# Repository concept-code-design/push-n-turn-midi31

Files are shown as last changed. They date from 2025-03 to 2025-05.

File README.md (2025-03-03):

# Push-n-Turn 31

Push-n-Turn 31 is a USB MIDI controller with 3 keyboard switches (RedDragon low profile), a rotary encoder and 3/4 RGB leds (WS8212).

The device sports a USB type-C connector and requires no device drivers on Mac or PC.

The keys can be configured (via MIDI messages, or the configurator) to produce notes, CC codes (momentary or toggle mode). The encoder produces 0..127 on a configurable CC channel. The encoder button produces 127/0 on a CC channel of choice.
Each switch has an RGB led that shows the state of the switch.
The device uses a modified midi library for CH55x devices made by mi:muz 

## Configuring the keys
Configuration of the keys can be done by sending midi codes to the device.
You can use python midiutil for this (https://github.com/sourcebox/midiutil).

start prog
./midiutil.py -d 1 -w 186 102 42

end prog
./midiutil.py -d 1 -w 186 102 43

module type
./midiutil.py -d 1 -w 186 102 44
returns: (10, 103, INSTRUMENT_TYPE);

firmware version
./midiutil.py -d 1 -w 186 102 45
returns (10, 104, FW_VERSION) 10 for version 1.0

show configuration
./midiutil.py -d 1 -w 186 102 46
returns the config of each of the 6 buttons, the rotary knob and rotary encoder

show stepsize 
./midiutil.py -d 1 -w 186 102 47
returns (10, 105, encStepSize)

show MIDI channel 
./midiutil.py -d 1 -w 186 102 48
returns (10, 106, MIDIChannel)

reboot in firmware update mode
./midiutil.py -d 1 -w 186 102 49

programming keys
./midiutil.py -d 1 -w 186 102 42
./midiutil.py -d 1 -w 186 11 60
./midiutil.py -d 1 -w 186 22 30
./midiutil.py -d 1 -w 186 33 9
./midiutil.py -d 1 -w 186 24 15
./midiutil.py -d 1 -w 186 5 24
./midiutil.py -d 1 -w 186 102 43

## Links & References

* [mi:muz:ch55x Tiny USB MIDI Library for Ch55xduino](https://github.com/mimuz/mimuz-ch55x)
* [push-n-turn-midi61](https://github.com/concept-code-design/push-n-turn-midi61)

# License

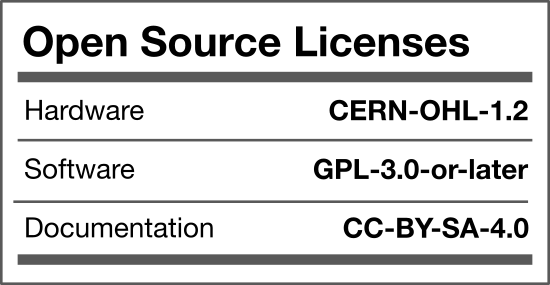
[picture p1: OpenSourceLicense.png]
OpenSourceLicense


Concept & Code invests time and resources providing this open source design, please support them and open-source hardware by purchasing products from Etsy or Tindie!

Designed by Ronald Leenes.

Firmware released under an GNU AGPL v3.0 license. See the LICENSE file for more information.

Hardware released under an CERN Open Hardware Licence v1.2. See the LICENSE_HARDWARE file for more information.

February 2025

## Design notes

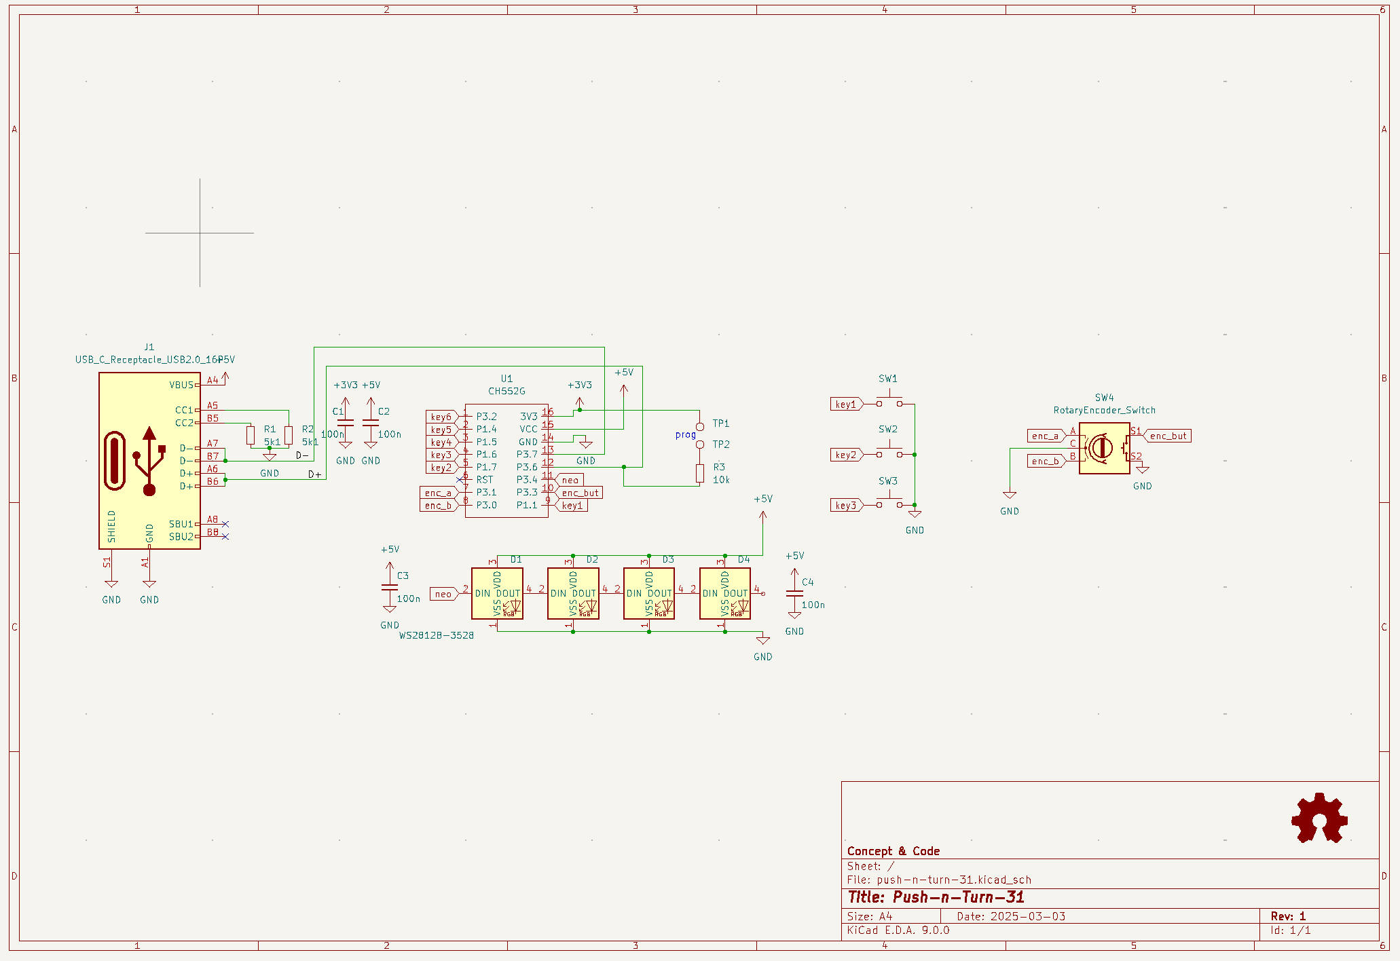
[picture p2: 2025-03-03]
hardware/push-n-turn-31.png

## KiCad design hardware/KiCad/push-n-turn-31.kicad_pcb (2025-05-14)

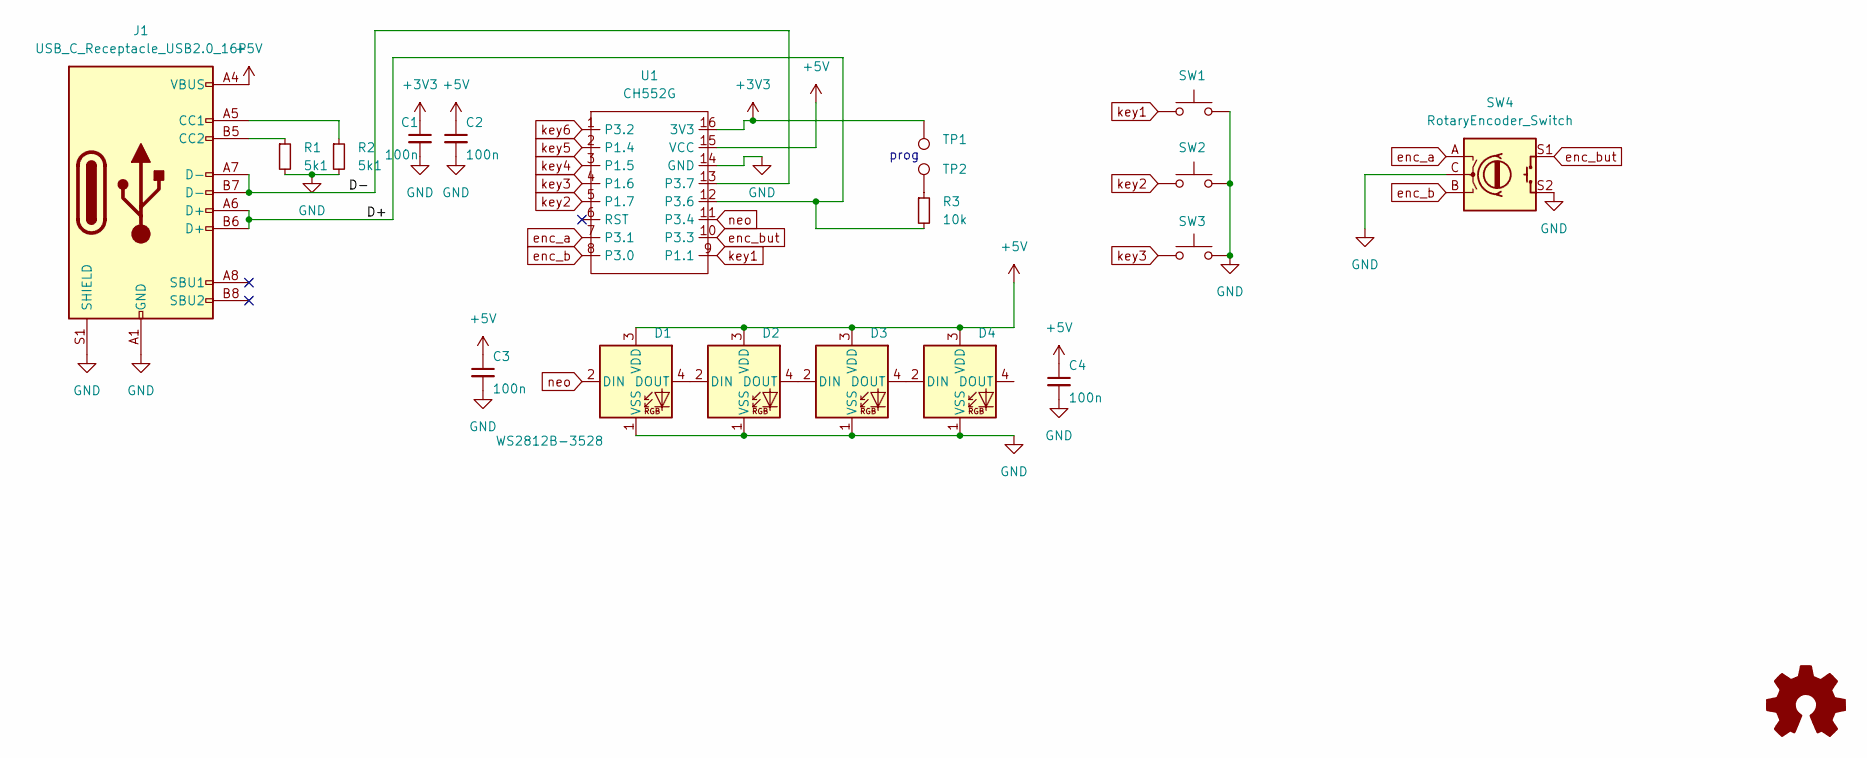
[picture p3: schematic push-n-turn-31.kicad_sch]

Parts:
C1, C2, C3, C4: 100n; C_0805_2012Metric
D1, D2, D3, D4: WS2812B-3528; LED_WS2812B-Mini_PLCC4_3.5x2.8mm
J1: USB_C_Receptacle_USB2.0_16P; USB_C_Receptacle_GCT_USB4105-xx-A_16P_TopMnt_Horizontal
R1, R2: 5k1; R_0805_2012Metric
R3: 10k; R_0805_2012Metric
SW1: key1; SW_RedDragon5.5m_Ali_1.00u
SW2: key2; SW_RedDragon5.5m_Ali_1.00u
SW3: key3; SW_RedDragon5.5m_Ali_1.00u
SW4: RotaryEncoder_Switch; RotaryEncoder_Alps_EC12E-Switch_Vertical_H20mm
TP1: TestPoint_Pad_2.5x2.5mm
TP2: TestPoint; TestPoint_Pad_2.5x2.5mm
U1: CH552G; SOP-16_4.4x10.4mm_P1.27mm

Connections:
+3V3: C1.1, TP1.1, U1.16 (3V3)
+5V: C2.1, C3.1, C4.1, D1.3 (VDD), D2.3 (VDD), D3.3 (VDD), D4.3 (VDD), J1.A4 (VBUS), J1.A9 (VBUS), J1.B4 (VBUS), J1.B9 (VBUS), U1.15 (VCC)
/D+: J1.A6 (D+), J1.B6 (D+), R3.2, U1.12 (P3.6)
/D-: J1.A7 (D-), J1.B7 (D-), U1.13 (P3.7)
GND: C1.2, C2.2, C3.2, C4.2, D1.1 (VSS), D2.1 (VSS), D3.1 (VSS), D4.1 (VSS), J1.A1 (GND), J1.A12 (GND), J1.B1 (GND), J1.B12 (GND), J1.S1 (SHIELD), R1.2, R2.2, SW1.2, SW2.2, SW3.2, SW4.C, SW4.S2, U1.14 (GND)
unnamed: D1.4 (DOUT), D2.2 (DIN)
unnamed: D2.4 (DOUT), D3.2 (DIN)
unnamed: D3.4 (DOUT), D4.2 (DIN)
unnamed: J1.A5 (CC1), R2.1
unnamed: J1.B5 (CC2), R1.1
unnamed: R3.1, TP2.1
enc_a: SW4.A, U1.7 (P3.1)
enc_b: SW4.B, U1.8 (P3.0)
enc_but: SW4.S1, U1.10 (P3.3)
key1: SW1.1, U1.9 (P1.1)
key2: SW2.1, U1.5 (P1.7)
key3: SW3.1, U1.4 (P1.6)
key4: U1.3 (P1.5)
key5: U1.2 (P1.4)
key6: U1.1 (P3.2)
neo: D1.2 (DIN), U1.11 (P3.4)

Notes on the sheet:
prog

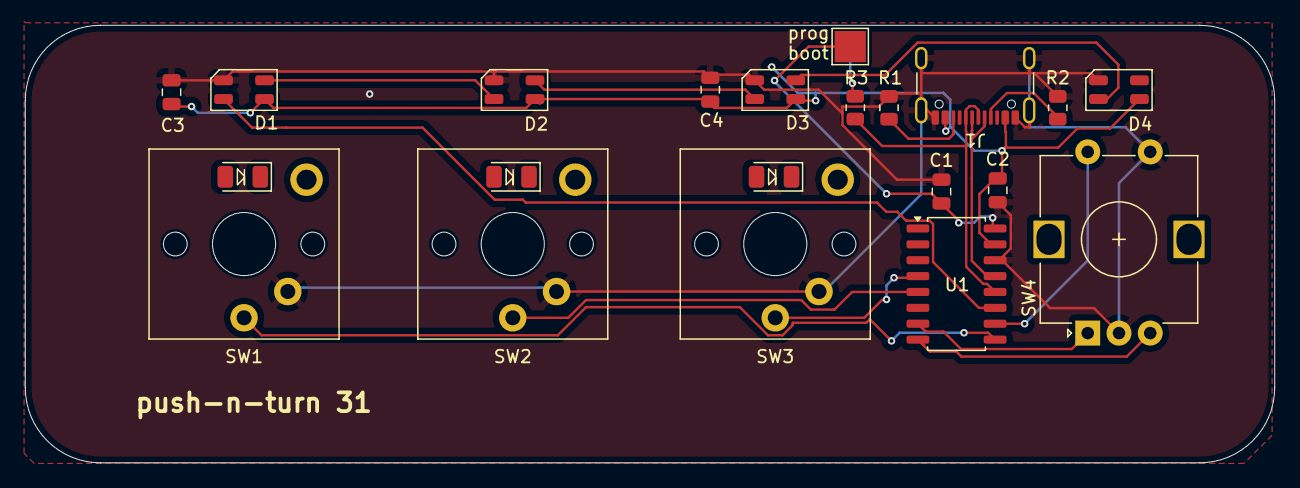
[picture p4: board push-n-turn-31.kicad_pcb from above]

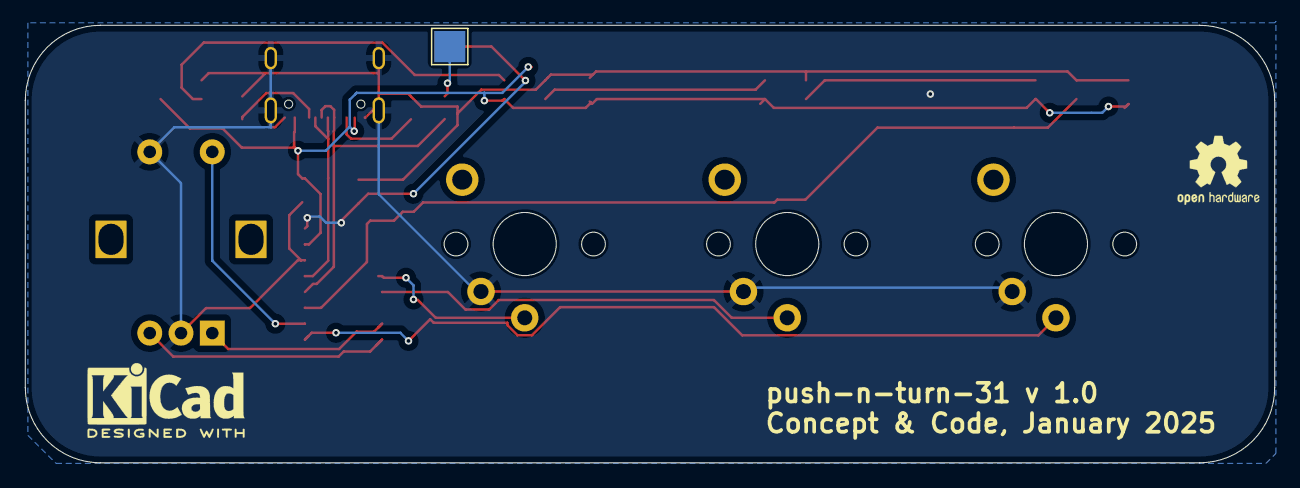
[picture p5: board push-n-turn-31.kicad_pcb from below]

Board: 2 copper layers, 100.0 x 35.0 mm, 21 parts (3 on the bottom side), 18 nets.

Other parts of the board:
KICAD: KiCad-Logo2_5mm_SilkScreen
REFOH: OSHW-Logo2_7.3x6mm_SilkScreen

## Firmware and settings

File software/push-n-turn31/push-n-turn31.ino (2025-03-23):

// ===================================================================================
// Project:   Push-n-Turn (31, 41, 61)
// Version:   v1.0
// Year:      2025
// Author:    Ronald Leenes
// Github:    https://github.com/concept-code-design
// License:   GNU AGPL v3.0 license
// ===================================================================================
//
// Description:
// ------------
// Firmware for the various Push-n-Turn midi controllers building on mimuz-ch55x midi library for CH55x chips
//
// References:
// -----------
// - D.F.Mac. : https://github.com/mimuz/mimuz-ch55x
// - WCH Nanjing Qinheng Microelectronics: http://wch.cn

#include "config.h"
#include "vars.h"
#include "push-n-turn.h"
#include "colors.h"
#include "mimuz-ch55x.h"
#include <WS2812.h>

#ifndef USER_USB_RAM
#error "This sketch needs to be compiled with a USER USB setting"
#endif

void setup(){
  init_PINS();
  if (NUM_ENCODERS > 0) init_ENCODER();
  readEEPROM();

  init_NEO();

  check_PROGBOOT_REQUEST();
  USBInit();
  setHdlCtlChange(onCTLChange);
}

void loop() {
  switchUpdate();
  if (NUM_ENCODERS > 0) encoderUpdate();
  processMidiMessage();
  USBSerial_flush();
}

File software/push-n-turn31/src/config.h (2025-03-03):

// ===================================================================================
// User Configurations for CH552G USB MacroPad Plus
// ===================================================================================

#pragma once
/*
// Pin definitions
#define PIN_NEO             P16         // pin connected to NeoPixel
#define PIN_KEY1            P17         // pin connected to key 1
#define PIN_KEY2            P31         // pin connected to key 2
#define PIN_KEY3            P30         // pin connected to key 3
#define PIN_KEY4            P15         // pin connected to key 4
#define PIN_KEY5            P14         // pin connected to key 5
#define PIN_KEY6            P32         // pin connected to key 6
#define PIN_ENC_A           P34         // pin connected to rotary encoder A
#define PIN_ENC_B           P33         // pin connected to rotary encoder B
#define PIN_ENC_SW          P11         // pin connected to rotary encoder switch

*/
// NeoPixel configuration
#define NEO_COUNT           3          // number of pixels in the string
#define NEO_RGB                         // type of pixel: NEO_GRB or NEO_RGB


// USB device descriptor
#define USB_VENDOR_ID       0x1189      // VID
#define USB_PRODUCT_ID      0x8890      // PID
#define USB_DEVICE_VERSION  0x0100      // v1.0 (BCD-format)

// USB configuration descriptor
#define USB_MAX_POWER_mA    150         // max power in mA 

// USB descriptor strings
#define MANUFACTURER_STR    'w','a','g','i','m','i','n','a','t','o','r'
#define PRODUCT_STR         'M','a','c','r','o','P','a','d'
#define SERIAL_STR          'C','H','5','5','2','x','H','I','D'
#define INTERFACE_STR       'H','I','D','-','K','e','y','b','o','a','r','d'
